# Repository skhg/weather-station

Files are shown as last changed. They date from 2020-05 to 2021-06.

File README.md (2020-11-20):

# weather-station
I wanted to experiment with building environmental sensors, and see if I could make homemade electronics that would survive in the outdoors. So I built a weather station based around the Arduino-compatible ESP8266 platform.

<p align="center">
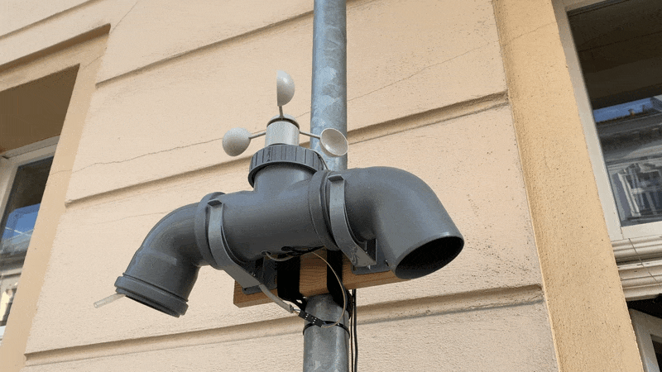
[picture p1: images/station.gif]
<br/>
<i>Weather station at work, in a light breeze. Most of the fun stuff is hidden inside that grey pipe.</i>
</p>

## Overview
There are many possible instruments that can be part of a weather station. For the amateur meteorologist, just a few are needed to make a start. They can all be bought cheaply online, and a weatherproof case can be made out of just a few short lengths of PVC piping. Credit to https://sensor.community for inspiration here - I based the system on this [reference design](https://sensor.community/en/sensors/airrohr/), with some additions for the extra sensors I wanted. The software is custom-made. See the [references](#references) section at the end for many useful links on how to build something similar yourself.

With this system we can measure:
 * Wind speed
 * Temperature
 * [Relative humidity](https://en.wikipedia.org/wiki/Relative_humidity)
 * [Air pressure](https://en.wikipedia.org/wiki/Atmospheric_pressure)
 * Air [particulate](https://en.wikipedia.org/wiki/Particulates) matter (PM2.5 and PM10)
 * Solar U.V. [intensity](https://en.wikipedia.org/wiki/Ultraviolet_index) - we can estimate the U.V. index
 * Rainfall (sort-of)
 
This is a wall-mounted device so wind direction wasn't really something I cared about for this project.

## Materials required

Sensors and electronics:

* [BME280](https://www.amazon.de/-/en/gp/product/B07D8T4HP6/ref=ppx_yo_dt_b_search_asin_title?ie=UTF8&psc=1) - Temperature, Humidity, and Air Pressure sensor
* [SDS011](https://www.amazon.de/-/en/gp/product/B07911ZY9W/ref=ppx_yo_dt_b_search_asin_title?ie=UTF8&psc=1) - Air particulate matter sensor (PM2.5 and PM10)
* [MH-RD](https://www.amazon.de/-/en/AZDelivery-Rain-Sensor-Module-Parent/dp/B07V5QQW9J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) - Rainfall droplet sensor
* [Froggit](https://www.amazon.de/-/en/gp/product/B00GGM5HEA/ref=ppx_yo_dt_b_search_asin_title?ie=UTF8&psc=1) - Anemometer
* [GY-8511](https://www.amazon.de/-/en/gp/product/B07PQPHJKR/ref=ppx_yo_dt_b_asin_title_o01_s00?ie=UTF8&psc=1) - Ultraviolet intensity sensor
* [NodeMCU ESP8266](https://www.amazon.de/-/en/gp/product/B074Q2WM1Y/ref=ppx_yo_dt_b_search_asin_title?ie=UTF8&psc=1) - Arduino-compatible microcontroller
* [JST headers](https://www.amazon.de/YIXISI-Connector-JST-XH-Female-Adapter/dp/B082ZLYRRN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)
* Digital/Analogue [multiplexer](https://www.amazon.de/-/en/gp/product/B06Y1L95GK/ref=ppx_yo_dt_b_search_asin_title?ie=UTF8&psc=1)
* 10kΩ [resistor](https://www.amazon.de/-/en/gp/product/B07Q87JZ9G/ref=ppx_yo_dt_b_search_asin_title?ie=UTF8&psc=1)
* [Ribbon cable](https://www.amazon.de/-/en/gp/product/B076CLY8NH/ref=ppx_yo_dt_b_search_asin_title?ie=UTF8&psc=1)
* [Perfboard](https://www.amazon.de/-/en/gp/product/B07BDKG68Q/ref=ppx_yo_dt_b_search_asin_title?ie=UTF8&psc=1)
* USB power supply

Case construction:

* 2x [45-degree drainpipe elbow](https://www.obi.de/ht-boegen/marley-ht-bogen-45-dn-75-grau/p/7436181)
* [Drainpipe with "cleaning" cap](https://www.obi.de/ht-reinigungsrohre/marley-ht-reinigungsrohr-dn-75/p/7434681)
* 2x [Gutter bracket](https://www.obi.de/kunststoff-dachrinnen/marley-rinnenhalter-verstellbar-dn-75-grau/p/5088869)
* [PTFE tape](https://www.amazon.de/-/en/Pack-Sealing-Thread-Teflon-White/dp/B071X6PC89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) for sealing joints
* Wooden board for mounting as required
* Rubber tube for air intake
* Insulating plastic/foam liner

UV Sensor module:
* Some little [wooden boards](https://www.amazon.de/-/en/gp/product/B07D76MKFY/ref=ppx_yo_dt_b_search_asin_title?ie=UTF8&psc=1)
* Small glass dome / [clock glass](https://www.amazon.de/-/en/gp/product/B00FWSFHBW/ref=ppx_yo_dt_b_asin_title_o04_s00?ie=UTF8&psc=1)
* Weather-resistant cabling
* Waterproof rubber gasket

## Circuit
The NodeMCU connects directly to the digital devices, and uses a multiplexer to read from the analog output devices. This diagram represents the anemometer as a "motor" - it generates signal pulses as it rotates on an axis.

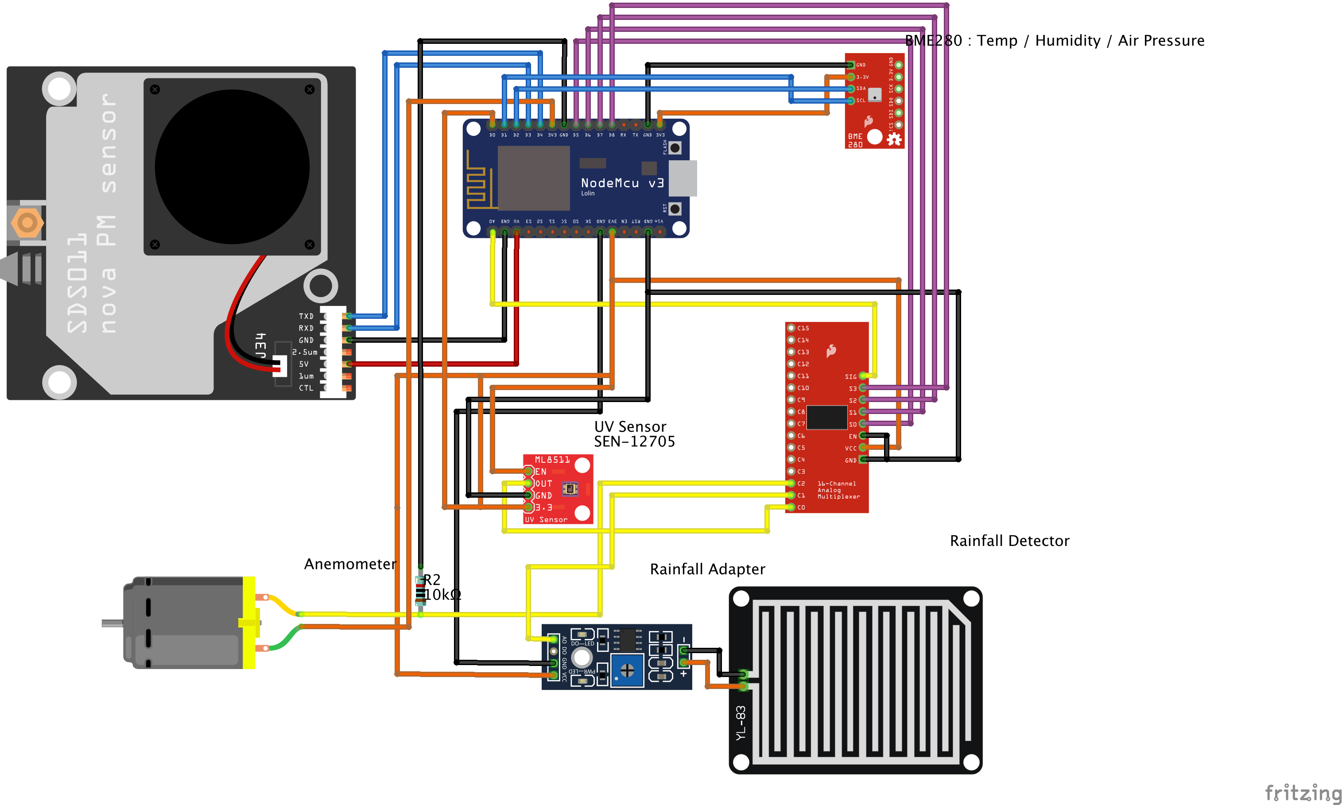
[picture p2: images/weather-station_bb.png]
<p align="center"><br/>
 <i>Circuit overview - export from fritzing <a href="weather-station.fzz">file</a></i></p>

The perfboard assembly was a little tricky because everything had to fit into a narrow package, and also be screwed on to the air quality board mounted directly underneath. This diagram shows how the two fit together. Those black squares on the perfboard show areas where holes were drilled to join the two together.

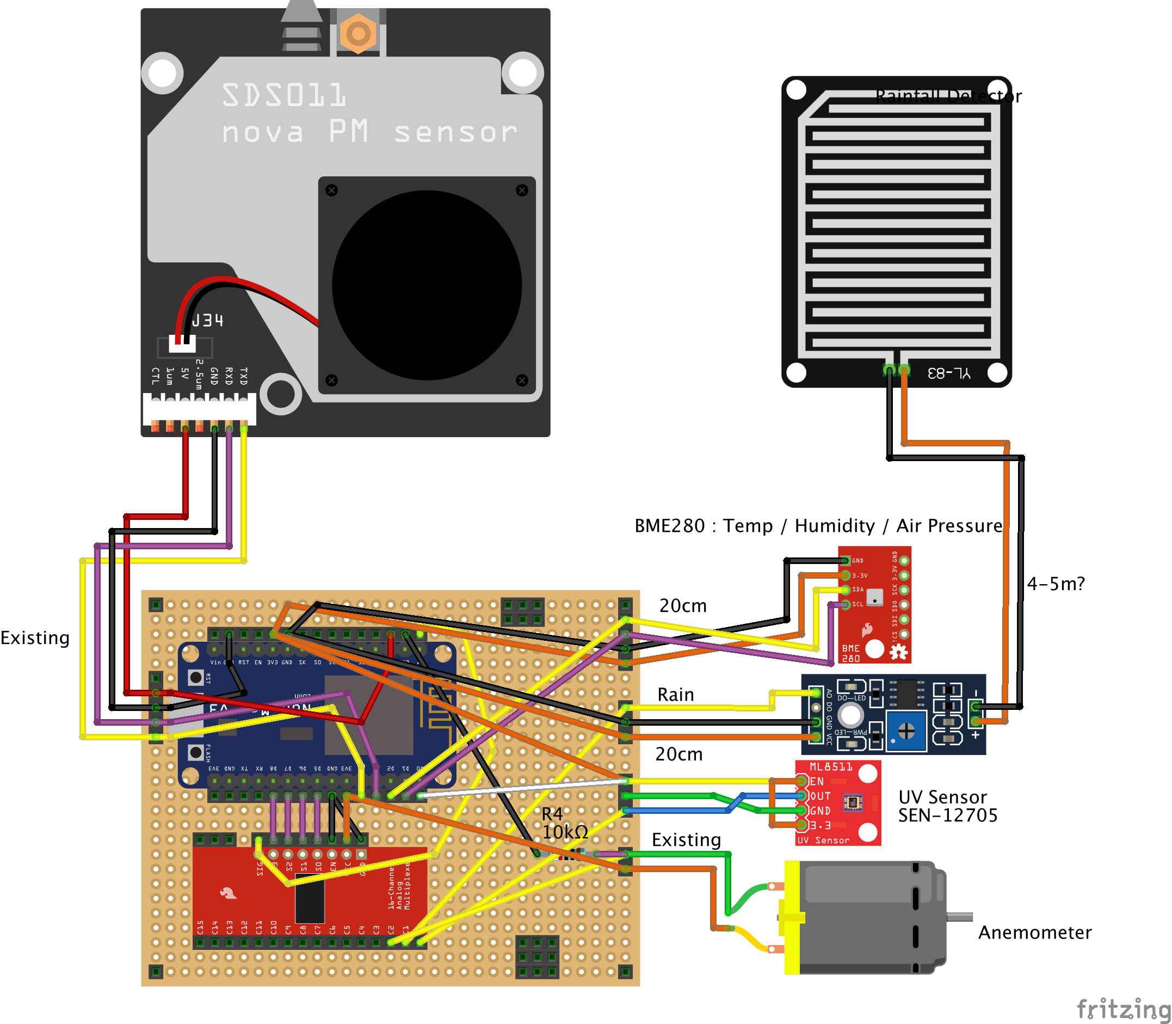
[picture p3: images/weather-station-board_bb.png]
<p align="center"><br/>
 <i>Perfboard and external components - export from fritzing <a href="weather-station-board.fzz">file</a></i></p>

The UV sensor is itself mounted on a small perfboard, which terminates the connection from the main case (It's mounted about 5m away and connected over Cat5 cable)

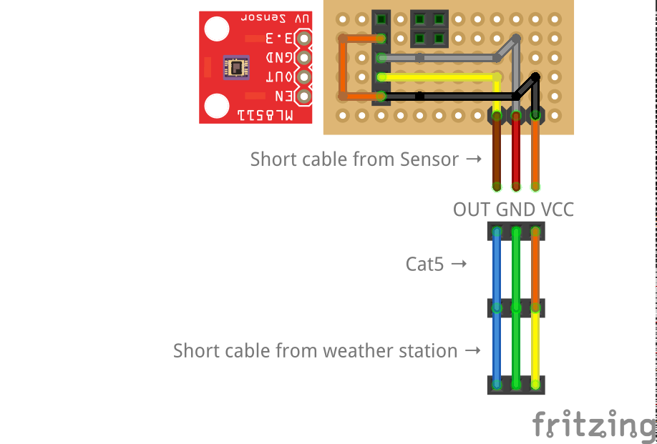
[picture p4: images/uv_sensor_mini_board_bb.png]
<p align="center"><br/>
 <i>UV sensor mini board - export from fritzing <a href="uv_sensor_mini_board.fzz">file</a></i></p>

## Assembly

First step was to make sure all the components were working together. I had tested them [individually](/testing) beforehand. Here they're all mounted on a breadboard with external components wired in too.

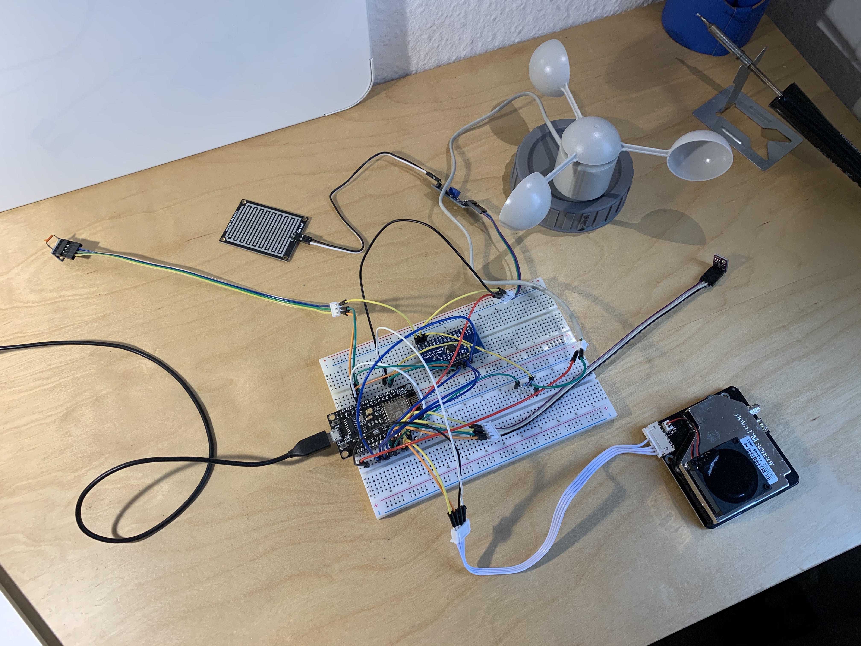
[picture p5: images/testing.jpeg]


Next step was soldering the perfboard and mounting the multiplexer, NodeMCU and wiring. Followed by mounting the air quality sensor underneath - with a layer of plastic and foam in between to prevent any short-circuits between exposed pins on the two devices.

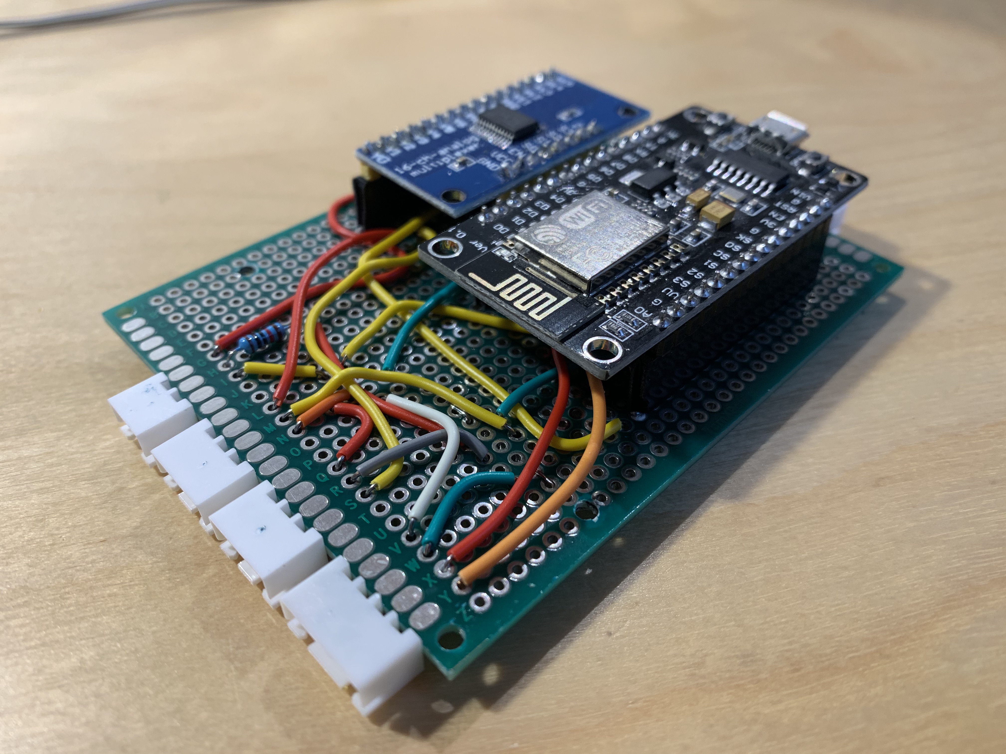
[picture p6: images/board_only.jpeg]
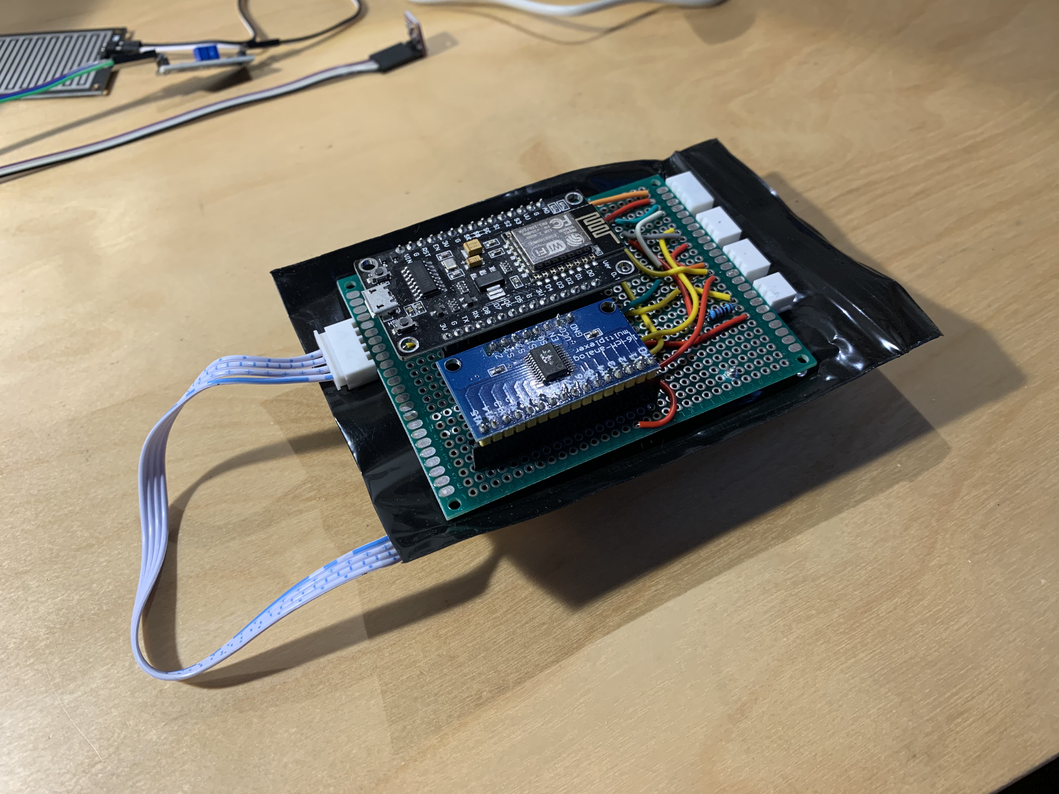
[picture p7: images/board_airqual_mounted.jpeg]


And sliding the complete unit into the case:

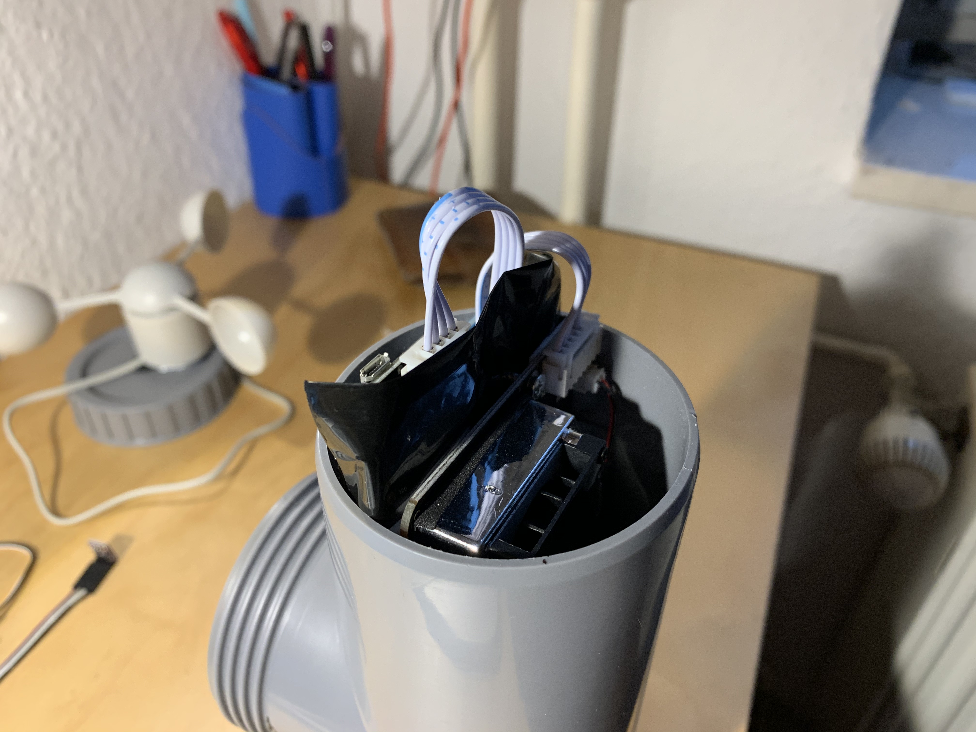
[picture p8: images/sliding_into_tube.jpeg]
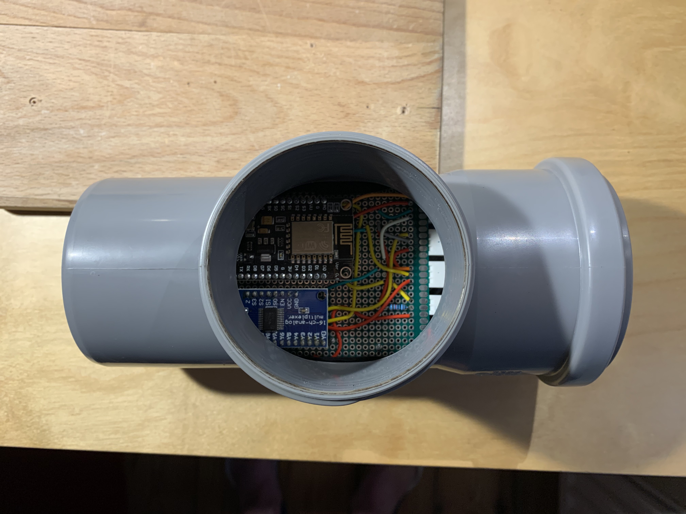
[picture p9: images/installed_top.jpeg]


It's a tight fit!

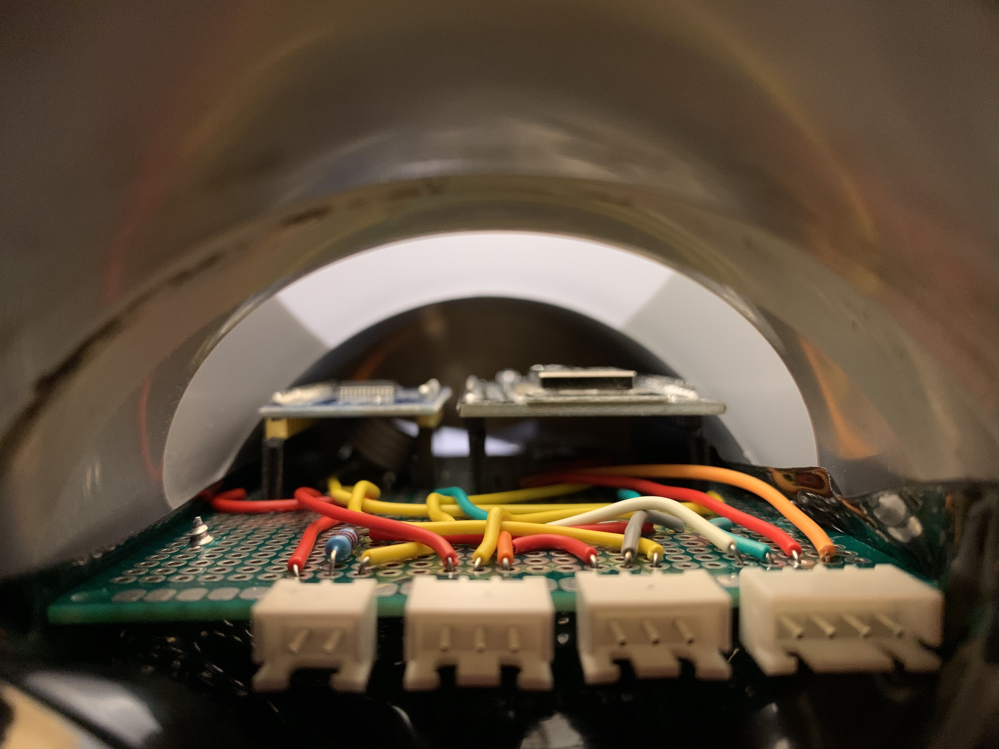
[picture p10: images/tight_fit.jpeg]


For the external UV sensor, I made a flat mount on a piece of board and painted it white, to keep moisture out and keep it cool in the sunshine. The UV sensor is protected from moisture by:
 * A white cap from a jar of skin cream
 * A rubber gasket from a coffee mokka
 * An inverted clock glass (with relatively high UV-transmissivity)
 * Some plastic chair leg-ends to clamp it together with some flexibility
 
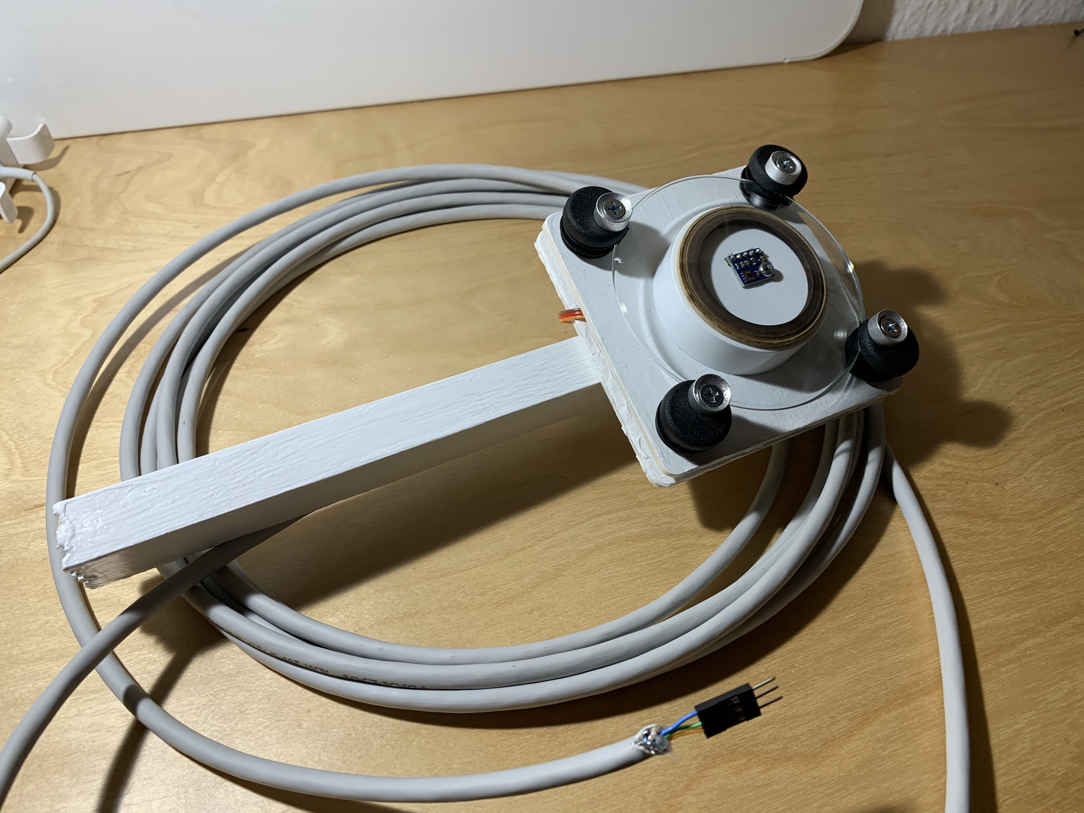
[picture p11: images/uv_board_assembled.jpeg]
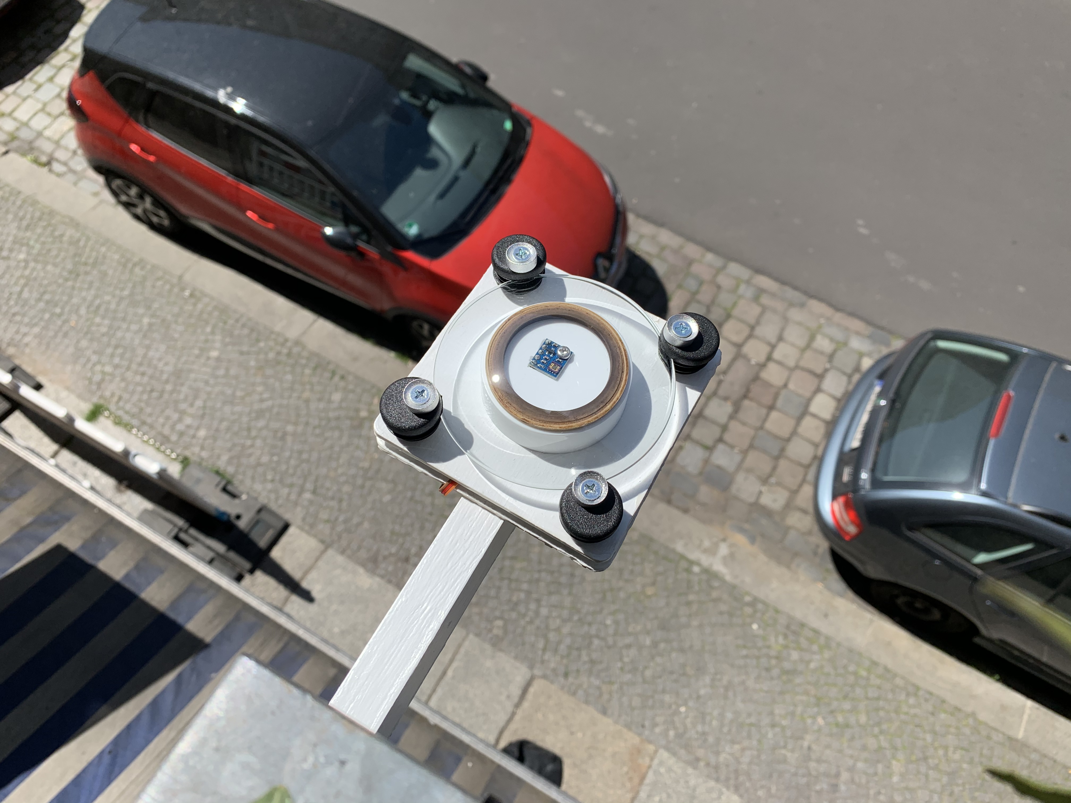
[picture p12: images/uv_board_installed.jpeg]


### Mounted in place

With everything in place and tightly fit together, it was time to install it in place on the balcony. We have a drainpipe that was a convenient place to attach it, as you can see in the <a href="#introduction">introduction</a>.

<p align="center">
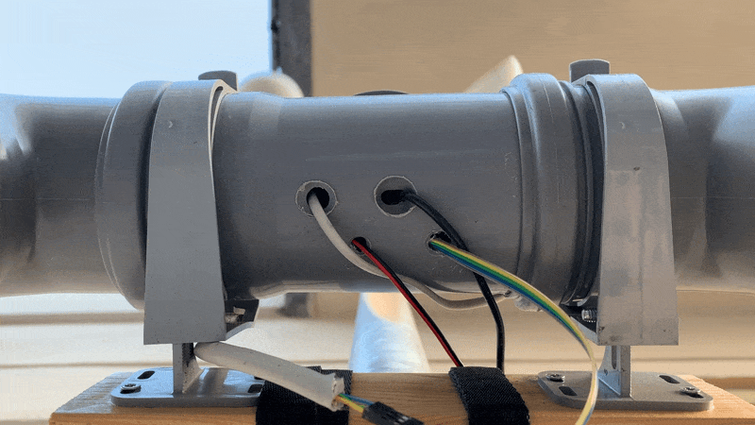
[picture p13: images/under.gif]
<br/>
<i>View from underneath. Holes for external connections in the middle here.</i>
</p>

<p align="center">
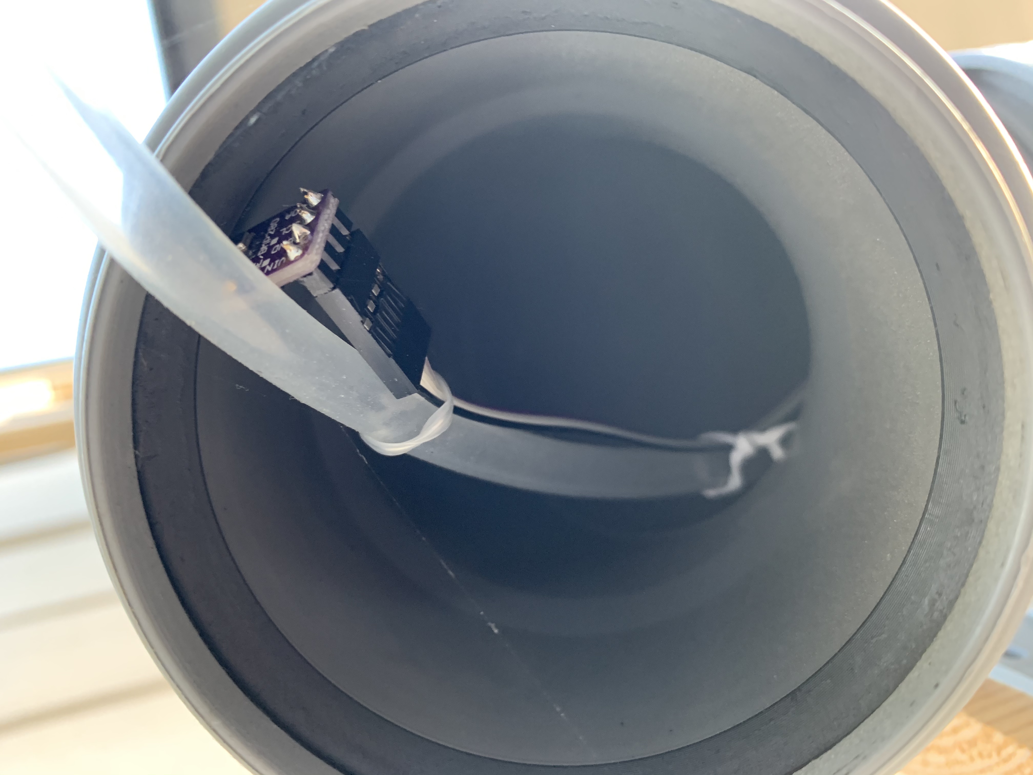
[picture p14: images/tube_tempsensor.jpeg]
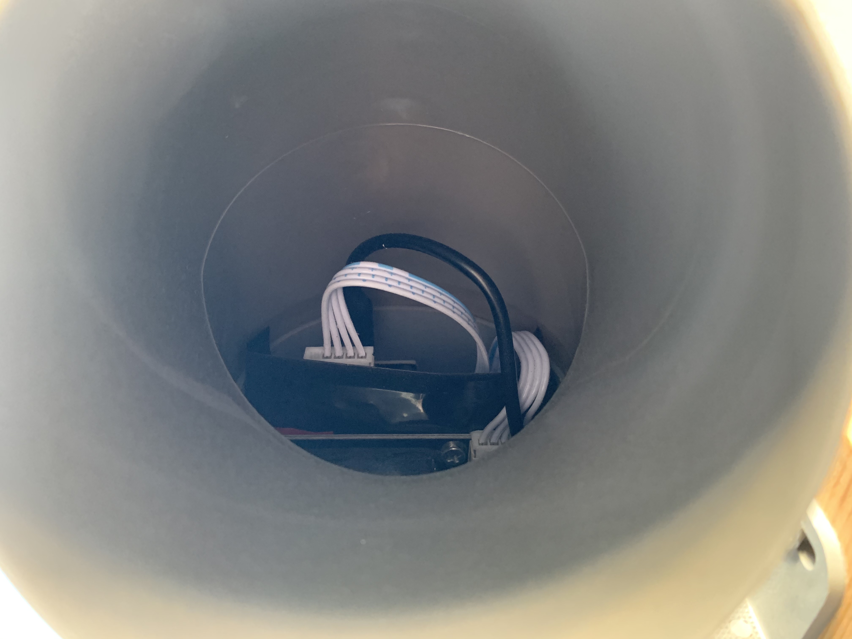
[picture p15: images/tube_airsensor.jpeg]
<br/>
<i>Views from the ends of either side of the main tube.<br/>Left: air intake tube and BME280 sensor. Right: rear of the SDS011 and exposed cabling.</i>
</p>

## Onboard software
The onboard [software](weather-station.ino) runs in a continuous loop. It captures the data, packages the results in a JSON blob, and sends them to a logging server on the local LAN. In case of any errors connecting to WiFi or to this server, it does a hard reboot. This is sufficient since the data is not time-critical, and up-to-date data is less important than an hourly/daily trend.



## Data Capture and Visualisation

Readings are packaged as a JSON blob and sent to a logging server on the local LAN, using a REST `POST` over HTTP. A sample message looks like:

```json
{
    "temperatureC" : 21.2,
    "humidityPercentage" : 34.2,
    "airPressurePa" : 1001000.2,
    "uvIntensityMilliwattsPerCmSq" : 3.2,
    "rainfallStrengthPercentage" : 10.2,
    "pm25density" : 10.1,
    "pm10density" : 9.8,
    "windSpeedKmPerHour" : 0.67
}
```

The logging server is a custom [Spring Boot](https://spring.io/projects/spring-boot) application. It logs the data to [InfluxDB](https://www.influxdata.com/), a time-series database. [Grafana](https://grafana.com/) is used for visualising the data.

<p align="center">
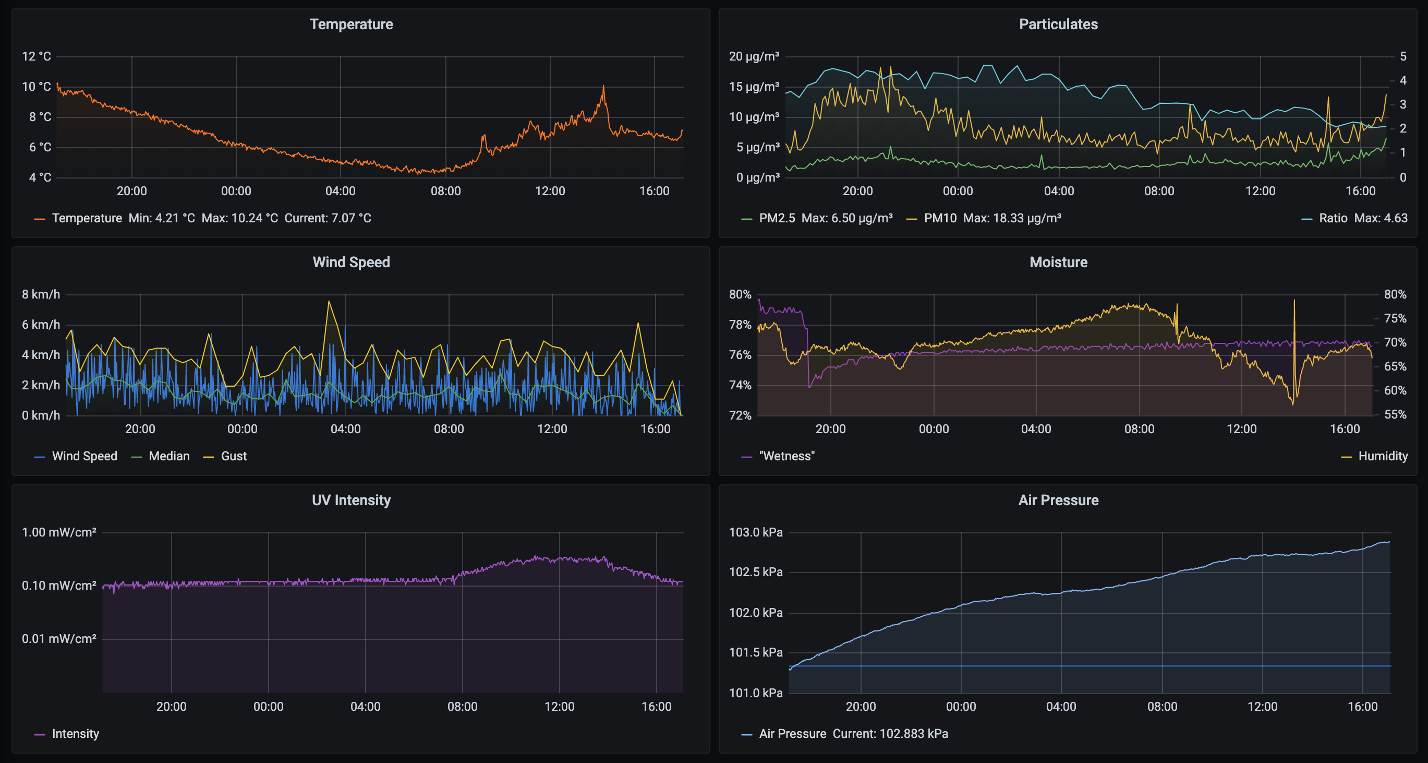
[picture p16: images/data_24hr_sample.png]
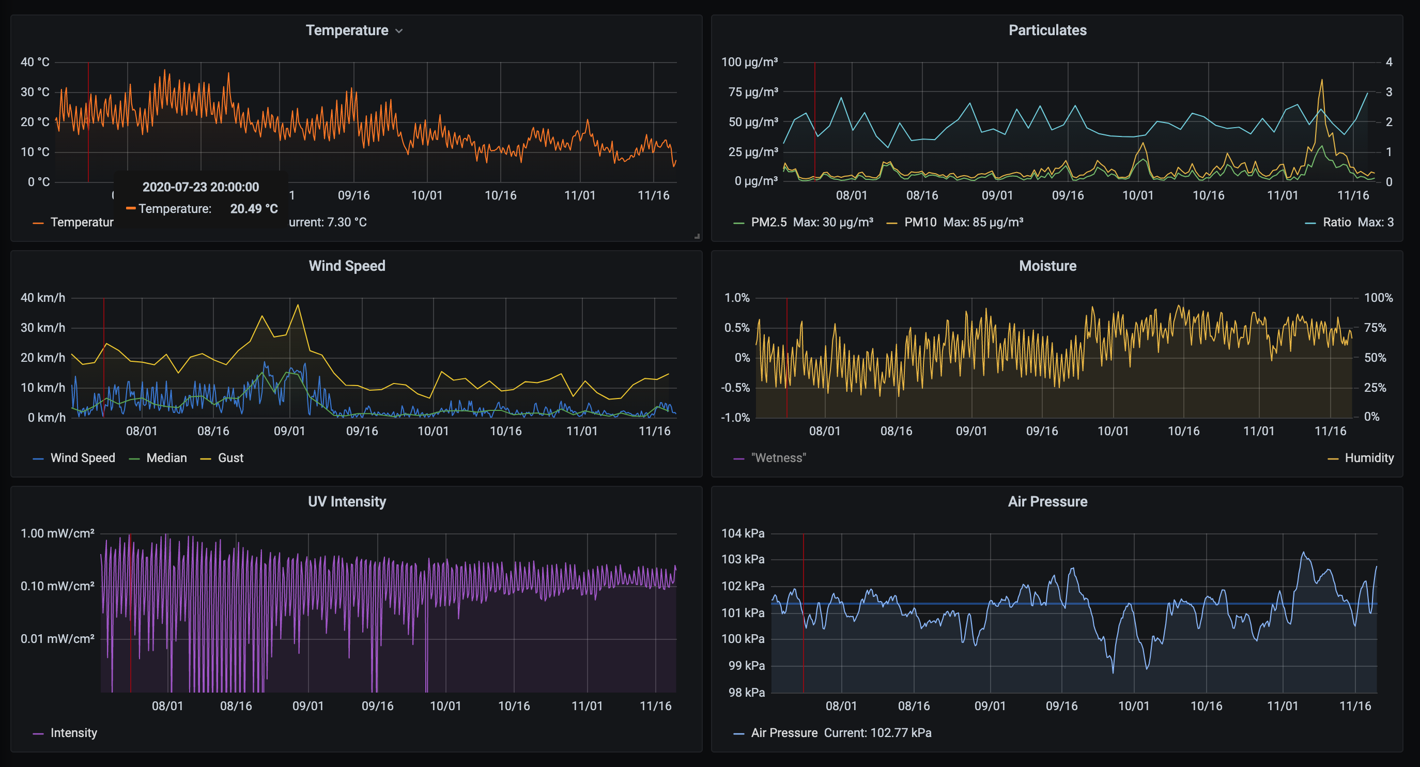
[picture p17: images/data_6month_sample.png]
 <br/>
<i>Screenshots of sample data from the Grafana dashboard.<br/>Left: 24 hours of data. Right: 6 months of data.</i>
</p>

## Performance over time
It survived its first summer with months of direct sunlight and internal temperatures up to 37°C. Will it survive its first winter, with ice and snow? Time will tell...

As of November 2020 it's been outside for over 6 months and still works, data seems consistent and matches what I see from the official weather reports. The only component that has significantly degraded is the rainfall sensor, which gives junk results now. Constant rainfall has eroded the resistive surface and left some kind of rust all over it. This should be replaced.

## Future enhancements

Rainfall sensor:
 * Replace with a better device that will not degrade so much over time. A capacitive option might be a good alternative with no moving parts.
 
Remove multiplexer:
 * I think I had some issues with analogue data reads the first time around, but it appears that the multiplexer board isn't actually required. I would remove this next time and connect external devices directly to the NodeMCU board.
 
Submit data online:
 * I would like to submit the recorded data from my server to https://luftdaten.info/, https://www.pwsweather.com/ or similar

Data validation:
 * The onboard software does no sanity checking of the data it reports back to the server. On at least one occasion this meant it reported a temperature of -143°C which was fixed by a hard reboot.
 * The software should include some hardcoded bounds outside which it will report an error status back to the server.

Case construction:
 * The anemometer is mounted into a hole drilled in the pipe cleaning cap. Next time I would rather mount the anemometer into a bracket that clips on top of that cap. Having a hole that has to be sealed with PTFE, right above the electronics, is likely to eventually fail due to water accumulation.
 * All the external connectors (USB power in, rainfall sensor, UV sensor, and anemometer cable) are routed through holes drilled in the bottom of the case. This doesn't look great, and makes it awkward/imposssible to disconnect them without disassembling the whole thing.
 * I would like to build a small "[patch panel](https://en.wikipedia.org/wiki/Patch_panel)" with JST connectors for all the external connections, that would be flat-mounted on the bottom of the case. A single USB connection for power/data would also be located here, so everything could be disconnected as needed without needing to open the whole thing up.

Air intake tube mount:
 * A 3D-printed mount for the air intake tube, [like this one](https://www.thingiverse.com/thing:3945004), would make the case look nicer and more professionally finished.

## References
* https://hackaday.io/project/165061-solar-powered-wifi-weather-station-v20#j-discussions-title - A solar-powered weather station combining several of the same sensors used here.
* https://www.geeky-gadgets.com/arduino-wind-speed-meter-anemometer-project-30032016/ - Converting an anemometer's analogue readings into a digital signal for wind speed
* https://learn.sparkfun.com/tutorials/ml8511-uv-sensor-hookup-guide/all - Using a UV intensity sensor
* https://gist.github.com/geoffwatts/b0b488b5a5257223ed53 - Using a PM2.5 air particulate sensor
* https://sensor.community/en/sensors/ - Reference designs for weather stations which I used as inspiration for this project
* https://sensor.community/en/sensors/airrohr/ - The specific example I based this project on
* https://learn.pimoroni.com/tutorial/sandyj/enviro-plus-and-luftdaten-air-quality-station - A similar project although based around the Raspberry Pi Zero platform
* https://www.aeq-web.com/anemometer-mit-dem-arduino-bauen/ - Reading from an anemometer using an Arduino Uno
* https://forum.arduino.cc/index.php?topic=616264.0 - Handling interrupts on a NodeMCU board
* https://github.com/Naesstrom/Airrohr-kit - A similar project using a PCB

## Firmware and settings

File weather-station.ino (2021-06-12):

/**
 * Copyright 2020 Jack Higgins : https://github.com/skhg
 * All components of this project are licensed under the MIT License.
 * See the LICENSE file for details.
 */

/**
 * Installation-specific settings
 */

// Transparency (0.0 to 1.0) of the glass cover on the UV sensor
#define UV_SENSOR_CAP_TRANSPARENCY 0.9

/**
 * Network Configuration
 */
#define WIFI_CONNECT_TIMEOUT_SECONDS 30

/**
 * Data logging server configuration
 */

#define SERVER_ADDRESS "http://192.168.178.29:8080"
#define URL_PATH "/weather-station/balcony"
#define HOSTNAME "weather-station"

/**
 * String defaults
 */
#define SEPARATOR_LINE "---"
#define HTTP_CONTENT_TYPE_HEADER "Content-Type"
#define HTTP_CONTENT_LENGTH_HEADER "Content-Length"
#define HTTP_JSON_CONTENT_TYPE "application/json"
#define EMPTY_STRING ""

/**
 * System properties
 */
#define REBOOT_DELAY_MS 1000

/**
 * Pin placements
 */
#define ANALOGUE_IN A0
#define REF_3V3 16  // D0
#define SDS_DUST_TX D3
#define SDS_DUST_RX D4
#define MULTIPLEX_S0 14  // D5
#define MULTIPLEX_S1 12  // D6
#define MULTIPLEX_S2 13  // D7
#define MULTIPLEX_S3 15  // D8

/** 
 *  Application below
 */

#include <home_wifi.h>
#include <ESP8266WiFi.h>
#include <Adafruit_BME280.h>
#include "SdsDustSensor.h"
#include <ArduinoJson.h>
#include <ESP8266HTTPClient.h>

/**
 * Instruments
 */
Adafruit_BME280 bme;
SdsDustSensor sds(SDS_DUST_RX, SDS_DUST_TX);

/**
 * Network messages
 */
WiFiClient WIFI_CLIENT;
HTTPClient HTTP_CLIENT;

/**
 * Runtime parameters
 */
uint64_t previousTime = 0;
float ultravioletDarknessVoltage = 1.07;
float ultravioletMaxVoltage = 2.8;
float maxUltravioletIntensityLevelAtLocation = 8.0;
int airMeasurementSeconds = 30;
int cycleIntervalSeconds = 80;  // Runs a bit more than every 2 minutes

void setup() {
  Serial.begin(115200);

  Serial.println("Booting");
  delay(REBOOT_DELAY_MS);  // Allow a moment for some sensors to initialise

  previousTime = millis();

  setupMultiplexer();
  setupInstruments();

  Serial.println("Setup complete!");
  Serial.println(EMPTY_STRING);
}

void loop() {
  double temperature;
  double humidity;
  double pressure;

  getBme280data(&temperature, &pressure, &humidity);

  double uvIntensity;
  getUvSensorData(&uvIntensity);

  startParticulateMeasurement();

  double windSpeed;
  getWindSpeedKmPerHr(&windSpeed);

  double pm25level;
  double pm10level;
  endParticulateMeasurement(&pm25level, &pm10level);

  if (connectToWifi()) {
    sendData(temperature, humidity, pressure, uvIntensity,
      windSpeed, pm25level, pm10level);
  }

  WiFi.disconnect();
  WiFi.forceSleepBegin();

  sleepUntilNext();
}

void sleepUntilNext() {
  Serial.println("Cycle complete.");
  Serial.println(SEPARATOR_LINE);
  Serial.println("Sleeping for " + String(cycleIntervalSeconds) +
  " seconds...");
  Serial.println(EMPTY_STRING);
  Serial.flush();

  delay(cycleIntervalSeconds * 1000);
}

void setActiveMultiplexerChannel(int channelNum) {
  digitalWrite(MULTIPLEX_S0, bitRead(channelNum, 0));
  digitalWrite(MULTIPLEX_S1, bitRead(channelNum, 1));
  digitalWrite(MULTIPLEX_S2, bitRead(channelNum, 2));
  digitalWrite(MULTIPLEX_S3, bitRead(channelNum, 3));
}

void setupMultiplexer() {
  pinMode(MULTIPLEX_S0, OUTPUT);
  pinMode(MULTIPLEX_S1, OUTPUT);
  pinMode(MULTIPLEX_S2, OUTPUT);
  pinMode(MULTIPLEX_S3, OUTPUT);
}

void setupInstruments() {
  Serial.println("Setup BME280...");
  // Temp/humidity/pressure sensor
  bme.begin(0x76);
  Serial.println(EMPTY_STRING);

  Serial.println("Setup SDS011...");
  // Dust sensor
  sds.begin();
  Serial.println(sds.queryFirmwareVersion().toString());
  Serial.println(sds.setQueryReportingMode().toString());
  sds.sleep();
  Serial.println(EMPTY_STRING);
}

void getBme280data(double*temperature, double*pressure, double*humidity) {
  double liveTemp = bme.readTemperature();
  double livePressure = bme.readPressure();
  double liveHumidity = bme.readHumidity();

  Serial.println("BME280");
  Serial.println(SEPARATOR_LINE);
  Serial.println("Temperature: " + String(liveTemp));
  Serial.println("Pressure: " + String(livePressure));
  Serial.println("Humidity: " + String(liveHumidity));
  Serial.println(EMPTY_STRING);

  *temperature = liveTemp;
  *pressure = livePressure;
  *humidity = liveHumidity;
}

void getUvSensorData(double*uvIntensity) {
  Serial.println("ML8511");
  Serial.println(SEPARATOR_LINE);
  setActiveMultiplexerChannel(0);
  int uvLevel = averageAnalogueRead(ANALOGUE_IN);
  int refLevel = averageAnalogueRead(REF_3V3);
  double outputVoltage = 3.3 / refLevel * uvLevel;
  double mapped = mapDouble(outputVoltage, ultravioletDarknessVoltage,
  ultravioletMaxVoltage, 0.0, maxUltravioletIntensityLevelAtLocation);
  double adjustedIntensity = mapped / UV_SENSOR_CAP_TRANSPARENCY;

  *uvIntensity = adjustedIntensity;

  Serial.println("UV sensor glass transparency: " +
  String(UV_SENSOR_CAP_TRANSPARENCY));
  Serial.println("UV sensor level: " + String(uvLevel));
  Serial.println("Reference level: " + String(refLevel));
  Serial.println("Output voltage: " + String(outputVoltage));
  Serial.println("UV Intensity (mW/cm^2): " + String(mapped));
  Serial.println("Adjusted UV Intensity (mW/cm^2): " +
  String(adjustedIntensity));
  Serial.println(EMPTY_STRING);
}

void startParticulateMeasurement() {
  Serial.println("SDS011");
  Serial.println(SEPARATOR_LINE);
  Serial.println("Waking up...");
  sds.wakeup();
}

void endParticulateMeasurement(double*pm25, double*pm10) {
  PmResult pm = sds.queryPm();
  if (pm.isOk()) {
    double newPm25 = pm.pm25;
    double newPm10 = pm.pm10;

    Serial.println("PM 2.5: " + String(newPm25));
    Serial.println("PM 10: " + String(newPm10));

    *pm25 = newPm25;
    *pm10 = newPm10;
  } else {
    Serial.print("Could not read values from sensor, reason: ");
    Serial.println(pm.statusToString());
  }

  WorkingStateResult state = sds.sleep();
  if (state.isWorking()) {
    Serial.println("Problem with sleeping the sensor.");
  } else {
    Serial.println("Asleep");
  }
  Serial.println(EMPTY_STRING);
}

void getWindSpeedKmPerHr(double*windSpeed) {
  Serial.println("Anemometer");
  Serial.println(SEPARATOR_LINE);
  setActiveMultiplexerChannel(2);

  uint64_t startTime = millis();

  Serial.print("Start time: ");
  Serial.println(millis());
  Serial.println("Measure for: " + String(airMeasurementSeconds) +
  " seconds...");

  int currentState = map(analogRead(ANALOGUE_IN), 0, 1024, 0, 1);
  int nextState = currentState;
  int stateChangeCount = 0;  // One state change corresponds to 1/4 rotation

  while ((uint64_t)(millis() - startTime) < airMeasurementSeconds * 1000) {
    nextState = map(analogRead(ANALOGUE_IN), 0, 1024, 0, 1);
    if (nextState != currentState) {
      stateChangeCount++;
      currentState = nextState;
    }
    delay(1);
  }

  Serial.println("End time: " + String(millis()));
  Serial.println("Recorded: " + String(stateChangeCount) +
  " state changes (1/4 rotations)");

  double windSpeedKmHr = static_cast<double>(stateChangeCount) /
  static_cast<double>(airMeasurementSeconds) * 1.2;

  Serial.println("Wind Speed: " + String(windSpeedKmHr) + " km/hr");
  Serial.println(EMPTY_STRING);

  *windSpeed = windSpeedKmHr;
}

void sendData(double temperature, double humidity, double pressure,
  double uvIntensity, double windSpeed, double pm25level,
  double pm10level) {
  StaticJsonDocument<JSON_OBJECT_SIZE(8) + 1000> dataJson;

  dataJson["temperatureC"] = temperature;
  dataJson["airPressurePa"] = pressure;
  dataJson["humidityPercentage"] = humidity;
  dataJson["uvIntensityMilliwattsPerCmSq"] = uvIntensity;
  dataJson["windSpeedKmPerHour"] = windSpeed;
  dataJson["pm25density"] = pm25level;
  dataJson["pm10density"] = pm10level;

  Serial.println("Sending data");
  Serial.println(SEPARATOR_LINE);
  String jsonString;
  serializeJson(dataJson, jsonString);

  HTTP_CLIENT.begin(WIFI_CLIENT, String(SERVER_ADDRESS) + String(URL_PATH));

  HTTP_CLIENT.addHeader(HTTP_CONTENT_TYPE_HEADER, HTTP_JSON_CONTENT_TYPE);
  HTTP_CLIENT.addHeader(HTTP_CONTENT_LENGTH_HEADER,
    String(jsonString.length()));
  int result = HTTP_CLIENT.POST(jsonString);

  Serial.print("Completed with response code: ");
  Serial.println(result);

  Serial.flush();
}

/**
 * The Arduino Map function but for floats
 * From: http://forum.arduino.cc/index.php?topic=3922.0
 */
double mapDouble(double x, double in_min, double in_max, double out_min,
  double out_max) {
  return (x - in_min) * (out_max - out_min) / (in_max - in_min) + out_min;
}

/**
 * Takes an average of readings on a given pin, returns the average
 */
int averageAnalogueRead(int pinToRead) {
  byte numberOfReadings = 8;
  unsigned int runningValue = 0;

  for (int x = 0 ; x < numberOfReadings ; x++)
    runningValue += analogRead(pinToRead);
  runningValue /= numberOfReadings;

  return(runningValue);
}

/**
 * System management functions
 */

boolean connectToWifi() {
  Serial.println(SEPARATOR_LINE);

  WiFi.forceSleepWake();

  if (WiFi.status() == WL_CONNECTED) {
    return true;
  }

  Serial.print("Connecting to ");
  Serial.println(WIFI_SSID);

  WiFi.hostname(HOSTNAME);
  WiFi.begin(WIFI_SSID, WIFI_PASSWORD);

  int connectAttempts = 0;
  int connectRetryInterval = 500;
  int rebootCountdown = WIFI_CONNECT_TIMEOUT_SECONDS * 1000;

  while (WiFi.status() != WL_CONNECTED) {
    delay(connectRetryInterval);

    Serial.print(".");

    rebootCountdown = rebootCountdown - connectRetryInterval;

    if (rebootCountdown < 0) {
      Serial.println(EMPTY_STRING);
      Serial.println("Failed to connect.");
      return false;
    }
  }

  Serial.println(EMPTY_STRING);
  Serial.println("WiFi connected");
  return true;
}

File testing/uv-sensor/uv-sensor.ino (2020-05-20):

  /* 
 ML8511 UV Sensor Read Example
 By: Nathan Seidle
 SparkFun Electronics
 Date: January 15th, 2014
 License: This code is public domain but you buy me a beer if you use this and we meet someday (Beerware license).

 The ML8511 UV Sensor outputs an analog signal in relation to the amount of UV light it detects.

 Connect the following ML8511 breakout board to Arduino:
 3.3V = 3.3V
 OUT = A0
 GND = GND
 EN = 3.3V
 3.3V = A1
 These last two connections are a little different. Connect the EN pin on the breakout to 3.3V on the breakout.
 This will enable the output. Also connect the 3.3V pin of the breakout to Arduino pin 1.

 This example uses a neat trick. Analog to digital conversions rely completely on VCC. We assume
 this is 5V but if the board is powered from USB this may be as high as 5.25V or as low as 4.75V:
 http://en.wikipedia.org/wiki/USB#Power Because of this unknown window it makes the ADC fairly inaccurate
 in most cases. To fix this, we use the very accurate onboard 3.3V reference (accurate within 1%). So by doing an
 ADC on the 3.3V pin (A1) and then comparing this against the reading from the sensor we can extrapolate
 a true-to-life reading no matter what VIN is (as long as it's above 3.4V).

 Test your sensor by shining daylight or a UV LED: https://www.sparkfun.com/products/8662

 This sensor detects 280-390nm light most effectively. This is categorized as part of the UVB (burning rays)
 spectrum and most of the UVA (tanning rays) spectrum.

 There's lots of good UV radiation reading out there:
 http://www.ccohs.ca/oshanswers/phys_agents/ultravioletradiation.html
 https://www.iuva.org/uv-faqs

*/

//Hardware pin definitions
int UVOUT = A0; //Output from the sensor
int REF_3V3 = 16; //3.3V power on the Arduino board, and the D0 pin

#define MULTIPLEX_S0 14 // D5
#define MULTIPLEX_S1 12 // D6
#define MULTIPLEX_S2 13 // D7
#define MULTIPLEX_S3 15 // D8

const float glassTransparency = 0.88; // 0.0 to 1.0

void setup()
{
  Serial.begin(9600);

  pinMode(MULTIPLEX_S0, OUTPUT);
  pinMode(MULTIPLEX_S1, OUTPUT);
  pinMode(MULTIPLEX_S2, OUTPUT);
  pinMode(MULTIPLEX_S3, OUTPUT);

  //make input 0 active
  digitalWrite(MULTIPLEX_S0, LOW);
  digitalWrite(MULTIPLEX_S1, LOW);
  digitalWrite(MULTIPLEX_S2, LOW);
  digitalWrite(MULTIPLEX_S3, LOW);
  
  pinMode(UVOUT, INPUT);
  pinMode(REF_3V3, INPUT);

  Serial.println("ML8511 example");
}

void loop()
{
  int uvLevel = averageAnalogRead(UVOUT);
  int refLevel = averageAnalogRead(REF_3V3);

  //Use the 3.3V power pin as a reference to get a very accurate output value from sensor
  float outputVoltage = 3.3 / refLevel * uvLevel;

  //todo in_min and in_max should be configurable depending on sensor behaviour
  float uvIntensity = mapfloat(outputVoltage, 1.07, 2.8, 0.0, 15.0); //Convert the voltage to a UV intensity level

  float correctedIntensity = uvIntensity / glassTransparency; // Adjustment to handle the glass cover on top of the sensor
  
  Serial.print("refLevel: ");
  Serial.print(refLevel);

  Serial.print(" ML8511 output: ");
  Serial.print(uvLevel);

  Serial.print(" / ML8511 voltage: ");
  Serial.print(outputVoltage);

  Serial.print(" / UV Intensity (mW/cm^2): ");
  Serial.print(uvIntensity);

  Serial.print(" / Corrected UV Intensity (mW/cm^2): ");
  Serial.print(correctedIntensity);

  Serial.println();

  delay(100);
}

//The Arduino Map function but for floats
//From: http://forum.arduino.cc/index.php?topic=3922.0
float mapfloat(float x, float in_min, float in_max, float out_min, float out_max)
{
  return (x - in_min) * (out_max - out_min) / (in_max - in_min) + out_min;
}

//Takes an average of readings on a given pin
//Returns the average
int averageAnalogRead(int pinToRead)
{
  byte numberOfReadings = 8;
  unsigned int runningValue = 0; 

  for(int x = 0 ; x < numberOfReadings ; x++)
    runningValue += analogRead(pinToRead);
  runningValue /= numberOfReadings;

  return(runningValue);  
}

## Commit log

2020-04-30 add testing code and diagrams
    [rainfall-sensor-testing.fzz, uv-sensor-testing.fzz, weather-station.fzz]
2020-04-30 testing code for AQ sensor
2020-05-02 testing the air sensor and anemometer
    [anemometer.fzz, testing-sds011.fzz, weather-station.fzz]
2020-05-03 layout and colours of the full set of instruments
    [weather-station.fzz]
2020-05-09 working on test code for all sensors and more diagrams
    [anemometer.fzz, bme280.fzz, rainfall-sensor-testing.fzz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]
2020-05-20 add board diagrams and include adjustment of 88% for UV sensor glass
    [uv_sensor_mini_board.fzz, weather-station-board.fzz, weather-station.fzz]
2020-11-18 add png exports of fritzing diagrams
    [uv_sensor_mini_board.fzz]
2020-11-20 sample data grafana screenshots
2020-11-25 Validation and compile steps (#2)
    * validation and compile steps
    * lint fixes
    * avoid problem printing times
    [anemometer.ino, sds011.ino, weather-station.ino]
2021-06-12 Reduce power consumption and use nicer libraries (#3)
    * remove rainfall measurement and change cycle interval
    * delete idea dir
    * remove exception legacy
    * lots of changes
    * linter fix
    [anemometer.ino, weather-station.ino]
